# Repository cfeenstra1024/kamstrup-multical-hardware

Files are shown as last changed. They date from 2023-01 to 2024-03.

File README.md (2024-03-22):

# Hardware for use with ESPHome and Kamstrup Multical 403

This repository contains a PCB and housing that can be used as the hardware to read the measurements from a Kamstrup Multical 403.
The PCB uses a 'D1 Mini' ESP8266 board. A software component for use in [ESPHome](https://esphome.io/) has been created.

Using this setup you can read measurements from the Kamstrup Multical (e.g. city heating) and publish the measurements to 
[Home Assistant](https://www.home-assistant.io/).

## Electronics
The Kamstrup Multical 403 uses an optical interface for communication. A PCB was designed that uses a mini-D1 ESP8266 board. The 
[PCB Gerbers](Electronics/PCB%20Gerbers) folder contains the 
required files to fabricate the PCB. The [PCB Components](Electronics/PCB%20Components) folder contains the BOM (bill of materials) and the component placement files. A special version for use with [JLCBCB](https://jlcpcb.com/) has been created for these.

The PCB has the following features:
- Optical interface for use with the Kamstrup meter
- Pulse counter (can be used with a proximity sensor to measure water consumption)
- 2 free open collector outputs
- 2 free inputs

### What you need
- Order (or build) the PCB with the transistors and resistors
- [IR LED 940 nm](https://www.amazon.com/HiLetgo-Infrared-Emitter-Receiver-Emission/dp/B00M1PN5TK)
- [IR Photo Diode 940 nm](https://www.amazon.com/HiLetgo-Infrared-Emitter-Receiver-Emission/dp/B00M1PN5TK)
- [D1 Mini ESP8266 board](https://www.amazon.com/Organizer-ESP8266-Internet-Development-Compatible/dp/B081PX9YFV)
- Optional: [Header pins](https://www.amazon.com/MCIGICM-Header-2-45mm-Arduino-Connector/dp/B07PKKY8BX)

### Images
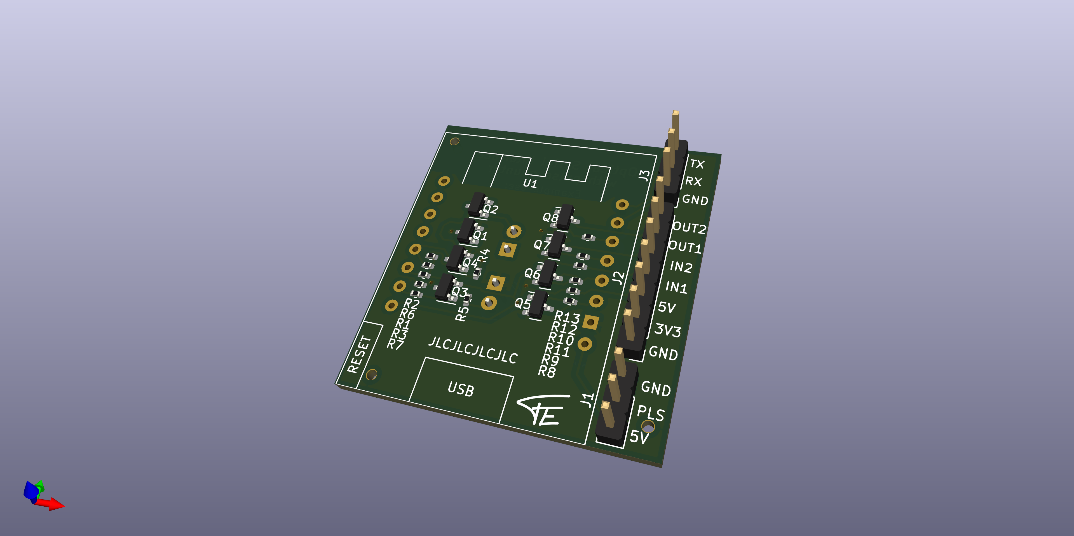
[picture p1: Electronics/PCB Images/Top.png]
PCB Top

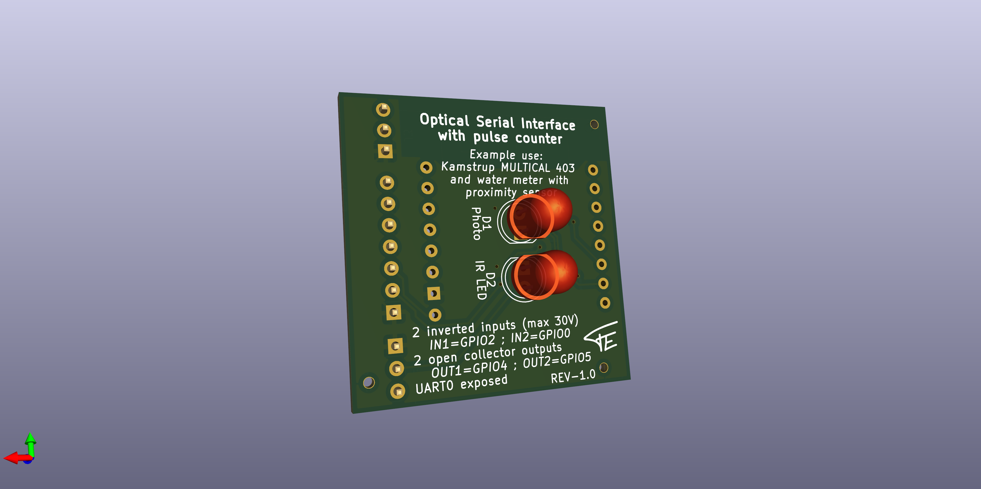
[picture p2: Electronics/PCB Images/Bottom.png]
PCB Bottom


## Housing

The housing can be 3D printed with a regular 3D printer. The [Fusion 360](Housing/Fusion-360) design and [STL](Housing/STL) files are provided.

The Kamstrup Multical 40x meter needs to be waken up by pressing a button. It then stays awake for a few minutes. To keep the meter awake, magnets must be placed 
in the 4 holes. Every hole fits 2 magnets (using a total of 8).

### What you need
- PCB printer to print the 2 STL files (housing and lid)
- 8x [6x3 mm neodymium magnets](https://www.amazon.com/MIN-Neodymium-Small-Magnets-6mm/dp/B096LZNZTQ)

### Images
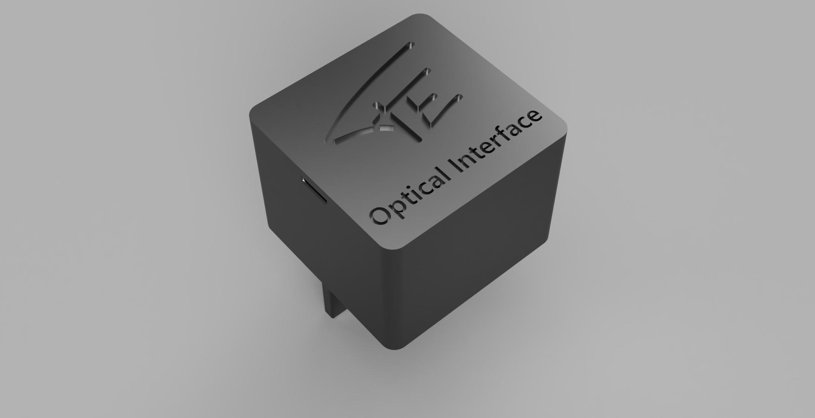
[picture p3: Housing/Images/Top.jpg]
Housing Top

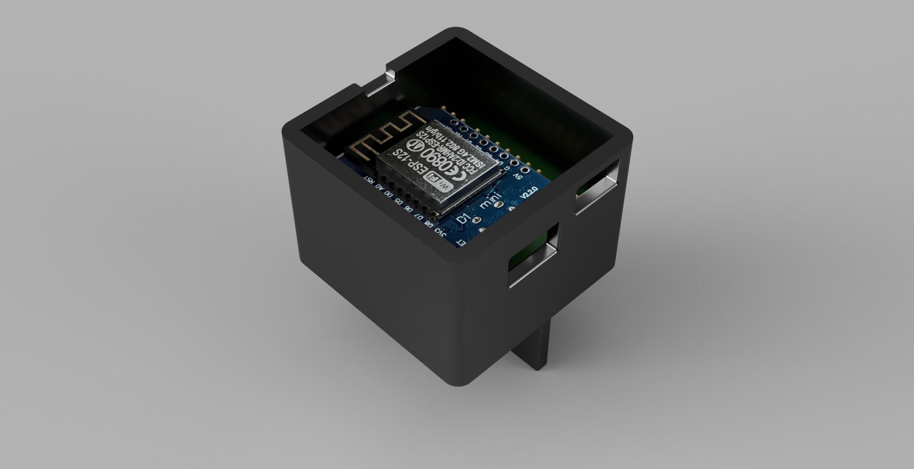
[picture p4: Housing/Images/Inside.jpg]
Housing Inside

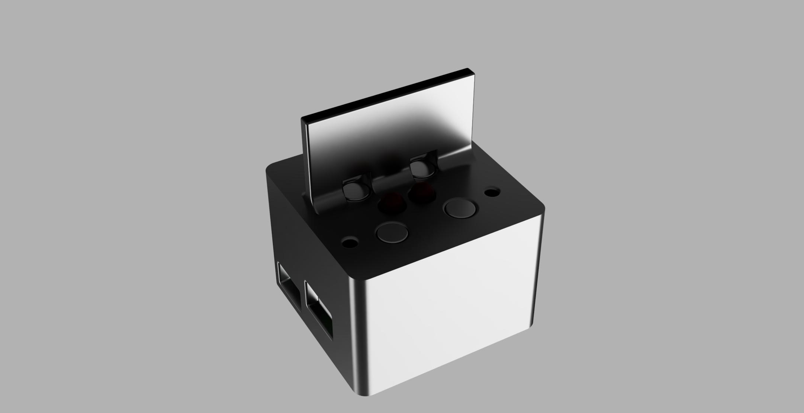
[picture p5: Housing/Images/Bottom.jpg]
Housing Bottom


## Software

Use the `kamstrup_kmp` component in ESPHome. Refer to the [Documentation](https://esphome.io/components/sensor/kamstrup_kmp) for all details regarding this component.

Example config file:
```yml
uart:
  baud_rate: 1200
  stop_bits: 2
  tx_pin: GPIO15
  rx_pin: GPIO13

sensor:
  - platform: kamstrup_mc40x
    heat_energy:
      name: 'Heat Energy'
    power:
      name: 'Heat Power'
    temp_diff:
      name: 'Heat Temperature Difference'
    flow:
      name: 'Heat Flow'
    custom:
      - name: Custom Heat Energy
        command: 0x003C
      - name: Custom Heat Power
        command: 0x0050
    update_interval: 60s
```

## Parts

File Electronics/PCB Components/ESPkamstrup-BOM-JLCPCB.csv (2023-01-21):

Comment | Designator | Footprint
S9013 J3 | Q8,Q2,Q4,Q5,Q1,Q7,Q6 | SOT-23
Conn_01x03_Male | J1,J3 | PinHeader_1x03_P2.54mm_Vertical
S9015 | Q3 | SOT-23
ESP8266_D1mini | U1 | ESP8266_D1mini
10k | R2,R8,R6,R11,R1 | R_0402_1005Metric
100 | R5 | R_0402_1005Metric
 | ,,
Conn_01x07_Male | J2 | PinHeader_1x07_P2.54mm_Vertical
39k | R12,R10,R9,R13,R7,R4 | R_0402_1005Metric
15k | R3 | R_0402_1005Metric
D_Photo | D1 | LED_D5.0mm
IR LED | D2 | LED_D5.0mm

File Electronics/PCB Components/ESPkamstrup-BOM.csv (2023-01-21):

Id | Designator | Package | Quantity | Designation | Supplier and ref
1 | Q8,Q2,Q4,Q5,Q1,Q7,Q6 | SOT-23 | 7 | S9013 J3
2 | J1,J3 | PinHeader_1x03_P2.54mm_Vertical | 2 | Conn_01x03_Male
3 | Q3 | SOT-23 | 1 | S9015
4 | U1 | ESP8266_D1mini | 1 | ESP8266_D1mini
5 | R2,R8,R6,R11,R1 | R_0402_1005Metric | 5 | 10k
6 | R5 | R_0402_1005Metric | 1 | 100
7 | ,, |  | 3
8 | J2 | PinHeader_1x07_P2.54mm_Vertical | 1 | Conn_01x07_Male
9 | R12,R10,R9,R13,R7,R4 | R_0402_1005Metric | 6 | 39k
10 | R3 | R_0402_1005Metric | 1 | 15k
11 | D1 | LED_D5.0mm | 1 | D_Photo
12 | D2 | LED_D5.0mm | 1 | IR LED

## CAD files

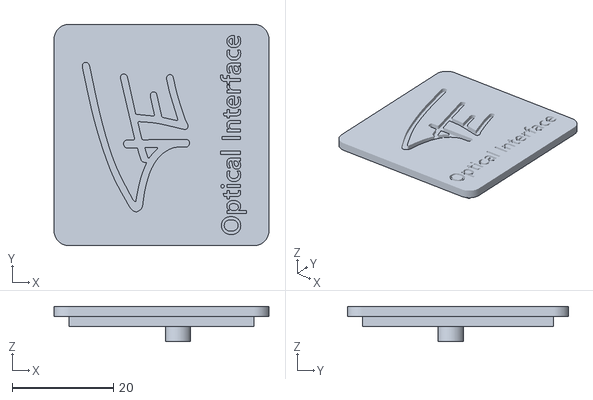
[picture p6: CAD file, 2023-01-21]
Housing/STL/Lid.stl
42.6 x 43.8 x 7.00

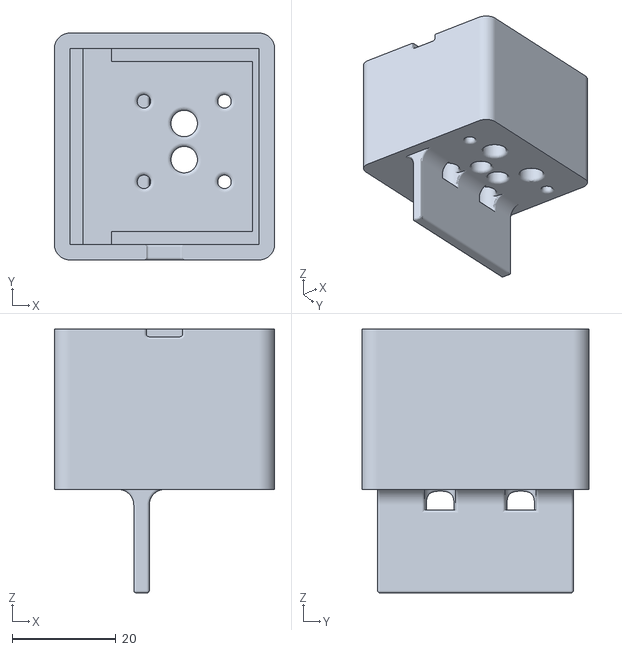
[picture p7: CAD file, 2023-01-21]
Housing/STL/Housing.stl
42.6 x 43.8 x 51.0

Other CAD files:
Housing/Fusion-360/Kamstrup Multical 403.f3z

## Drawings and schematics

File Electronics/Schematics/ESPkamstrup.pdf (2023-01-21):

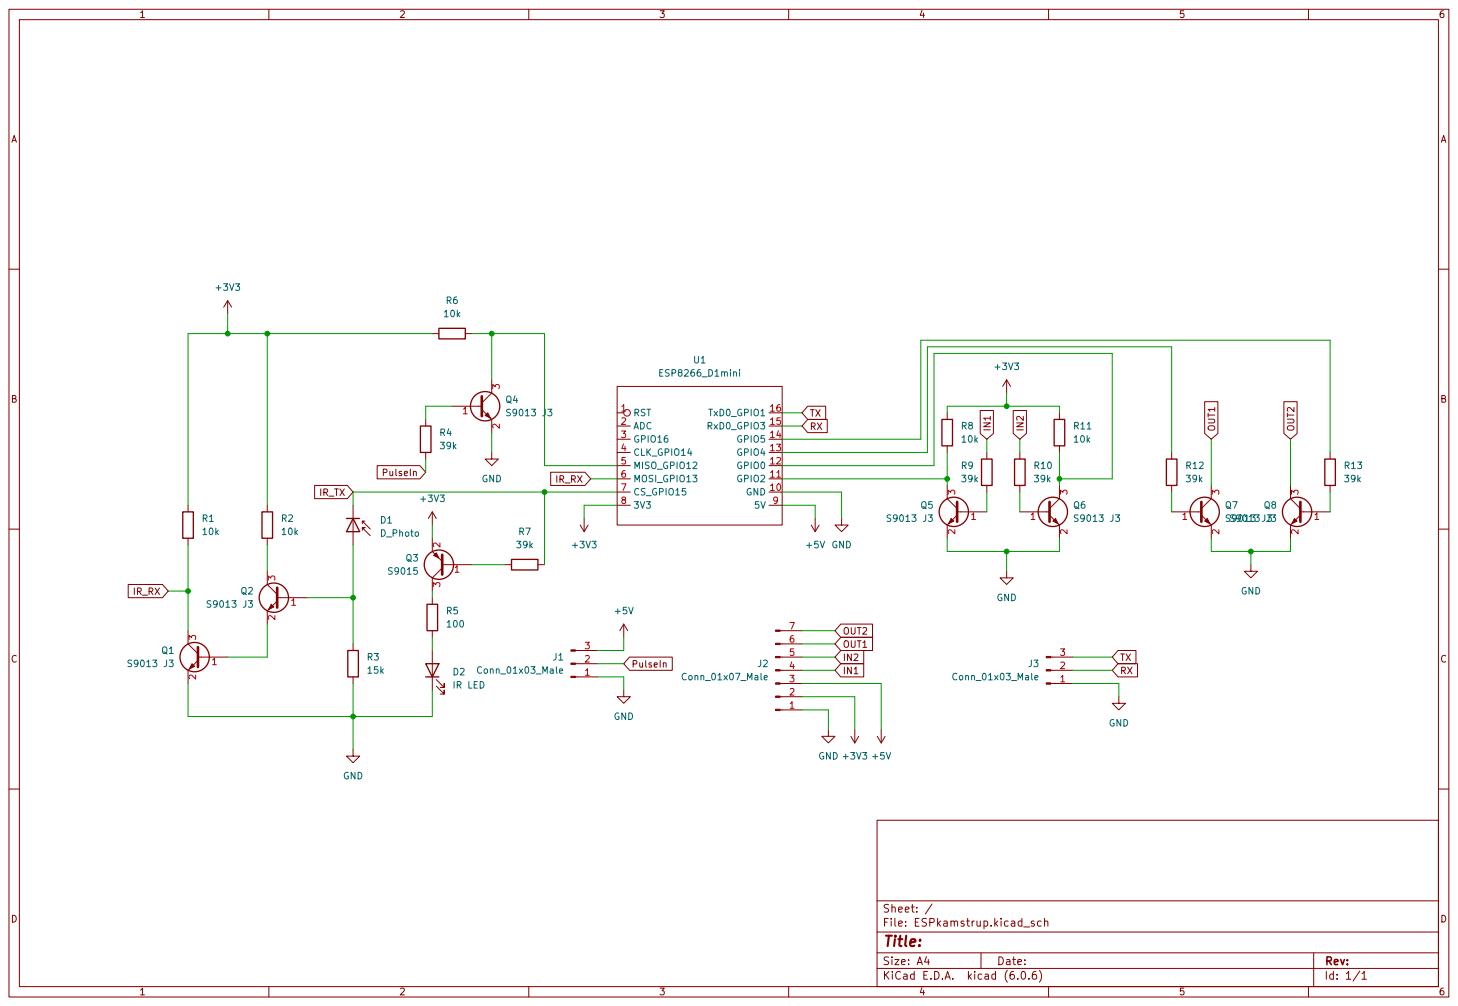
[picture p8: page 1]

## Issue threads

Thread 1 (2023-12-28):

Improve component with extra registers for multiple device types

htvekov, 2023-12-28:
Hi' @cfeenstra1024

Still waiting for the ESPHome PR to be merged before testing 🙂
I'm currently using ESPHome with my own 'tweaked' version of @cenobitedk Kamstrup custom component. Both for my district heating meter (Multical 602) as well as my water meter (flowIQ 2200).

I would suggest that you add the High Resolution register(s) to your component as well. For the x03 meter series it's a straight forward process. For the x02 series it's a bit more complicated as the HiRes register is a delta value. I've also added a calculated yearly cooling average sensor. Very useful in countries where the utility companies enforce 'penalty' tariffs for customers not cooling the water sufficiently. Reading the Unit Of Measurement from the actual device would also be a nice feature (not sure if you've already done that ?)

You could take a peek at my [fork](https://github.com/htvekov/esphome_multical402) if you're interested 🙂

cfeenstra1024, 2024-01-02:
Hi @htvekov,

Nice, you have different meters than I have. I only have a Multical 403. The component I created has native support for some of the most common registerers like 'Heat Energy' and 'Power'. However, you can add any number of registers yourself using the config file. See an example below that reads the high resolution register you've mentioned. I did not really want to add all possible registers in the component, but instead allow the (advanced) user to enter the register IDs themselves.

Once the PR is merged, I am open to extending the list of sensors. But I'm really keen to have this component first in ESPHome, before I disturb reviewers with more commits ;)

I also thought about using the unit read from the device, and set that to the sensor. However, this seems not to be possible / allowed. After I'd created this, I received [some comments](https://github.com/esphome/esphome/pull/4200#pullrequestreview-1347750261) about that in the PR.

A documentation PR is also pending, explaining the config options. As long as this PR is open, you can check it out [here](https://deploy-preview-3513--esphome.netlify.app/components/sensor/kamstrup_kmp).

```yaml
uart:
  baud_rate: 1200
  stop_bits: 2
  tx_pin: GPIO15
  rx_pin: GPIO13

sensor:
  - platform: kamstrup_kmp
    heat_energy:
      name: 'Heat Energy'
    power:
      name: 'Heat Power'
    temp_diff:
      name: 'Heat Temperature Difference'
    flow:
      name: 'Heat Flow'
    temp1:
      name: 'Temp 1'
    temp2:
      name: 'Temp 2'
    volume:
      name: 'Volume'
    custom:
      - name: 'High Resolution Heat Energy'
        command: 0x010A
        unit_of_measurement: 'Wh'
      - name: 'Some other custom sensor (Power)'
        command: 0x0050
```

cfeenstra1024, 2024-01-04:
I'll think about how I can add the different registers in a way the code stays maintainable and the configuration in the yaml file is not too complex.
The custom sensor supports any number of registers (it is a list). So no limitation to 5 any more.

htvekov, 2024-01-04:
For the Kamstrup FlowIQ 2200 meter following registers imo are the most relevant. Flow and volume registers are identical with the 40x/60x meters.

As this meter can detect both leak, burst, dry and tamper I'm currently searching for relevant Multical 21/FlowIQ 2x00 meter register info. So far I've not been able to find any info that confirms that these actually are the right registers for the info bit register and the reverse flow. The three lsb's should represent the actual event. Remaining bits should be a 'coarse' time indication for the duration. I'm not really keen to do a real life test on the information register - simulating a leak by running the tap for 24 hours 😉

The meter should also be able to report both ambient- and inlet water average temperature. I'm currently trying to identify these registers manually. So far no luck. But I've identified other registers such as max. flow pr. day etc.

```
0x00F3, // 0243 - V1 reverse flow					UOM 0x0028 (40 dec.): 'm³'
0x004A, // 0074 - Current water flow	 			UOM 0x0029 (41 dec.): 'l/h'
0x0044, // 0068 - Volume register V1				UOM 0x0028 (40 dec.): 'm³'
0x0063, // 0099 - Information						UOM 0x0033 (51 dec.): 'No unit'
0x03EC  // 1004 - Operating hour counter			UOM 0x002E (46 dec.): 'h'
```

htvekov, 2024-01-04:
I would still add the district heating HiRes Energy register though. This is highly usable to get more precise and detailed hourly readings e.g. in HA's Energy dashboard. Confirmed working on the new meter series. Not really sure what register the 402 meter is using. Should be 0x009B, but not confirmed.

```
0x010A, // 266 - Heat energy - Multical 403/603 High resolution (1 Wh)
0x009B  // 155 - Heat energy - Multical 602 High resolution (0.01 kWh)
```

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

htvekov, 2024-01-05:
Well, it seems that the HiRes register values differs depending on utility company/country.

If you check the cross referenced link further up this thread, two users have confirmed that the HiRes register is working as expected.

A Danish guy with a 403 meter (configured to return energy consumption in kWh). Here the HiRes register is also reported in kWh but with 3 decimals.
Also Dutch guy using a 603 meter with consumption i GJ for the 'normal' energy register. Here the HiRes register is reported in MWh with 5 decimals.

It seems that your HiRes register is returning a 'delta' value just a I get with my 602 meter. I guess that I've triggered my register at some point when I first attached the IR optical head - And it has been running ever since (4 months or so).
Upon ESPHome boot I deduct the HiRes register from the 'normal' energy register and store that difference as a constant. I add that constant to the HiRes register and return that value as my 'real' HiRes register.

cfeenstra1024, 2024-03-22:
FYI : The component has been merged and is now part of ESPHome (version >= 2024.3.0)

cenobitedk, 2024-03-22:
That's awesome @cfeenstra1024 💯

Closed 2024-05-02.

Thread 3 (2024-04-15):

jlcpcb BOM not working anymore + CPL file missing

sboldt1978, 2024-04-15:
Hi,

this is a really great project and I would like to implement this in my home as well - ordered via jlcpcb. I don't know if the changed something in the input files format, but now they request a CPL file (Pick&Place File) which I cannot find in the github files. Futhermore in the BOM file there are several components that cannot be matched (even when I use the special jlcpcb file. Can someone with better electronic knowledge than I have please update the BOM file and add the CPL file so that I - and everyone else who will get the stuff from jlcpcb.com can be sure to order the right parts?

Thanks a lot in advance!

best regards,
Stephan

frustreermeneer, 2024-04-16:
@sboldt1978 If you figure it out, maybe we can buy together?

cfeenstra1024, 2024-04-16:
I'll try to find some time to update the production files.
It is possible to order still, but you need to do some manual steps:

* Zip all files in the *PCB Gerbers* folder
* Upload the zip on JLCPCB
* Use the default settings, except for:
  * Set *Remove Order Number* to *Specify a location*
  * Enable the *PCB Assembly* option
  * Set *Tooling holes* to *Added by Customer*
* In the assembly wizard, you need to upload a BOM and CPL file:
  * BOM file is: *Electronics\PCB Components\ESPkamstrup-BOM-JLCPCB.csv*
  * CPL file is: *Electronics\PCB Components\ESPkamstrup-all-pos-JLCPCB.csv*
* See screen shot below for the component numbers I have used in my order (the C-numbers in the 'Matched Part Detail' column)
* In the *Component Placements* tab, check that all components are placed correctly. By default the transistors are rotated 180 degree. So do correct those. Select one and hit the spacebar twice to rotate. See screen shot below on how this should look at the end.

Sorry for the inconvenience. I will update the production files so all of the above will be set correctly automatically, but I cannot promise when I've time for this.

BTW: I do have a couple of these PCBs available. I could send you one if the shipping costs are reasonable from the Netherlands. If interested, please PM me through the [Home Assistant commutity](https://community.home-assistant.io/u/cfeenstra/summary).

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

sboldt1978, 2024-04-16:
Hi @cfeenstra1024 ,

I live in Germany, so shipping costs should be not too high from NL :-) May be I'm too stupid but I didn't find a way to send you a pm through the HA community :-( Can you please drop me a message here: https://community.home-assistant.io/u/sboldt1978/

Thanks a lot and best regards,
Stephan

frustreermeneer, 2024-04-16:
>  May be I'm too stupid but I didn't find a way to send you a pm through the HA community :-( Can you please drop me a message here: https://community.home-assistant.io/u/sboldt1978/

I have the same, you can't send PM's when you're new i guess.
My profile is https://community.home-assistant.io/u/frustreermeneer/
I'm not sure if i can receive PM's though...

morotsgurka, 2024-09-24:
Hi! I've updated the files in PR #5 with these changes it should fix all problems mentioned in this issue regarding ordering from JLCPCB. Hope it helps!

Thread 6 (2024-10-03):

GPIO pins valid?

MTrab, 2024-10-03:
I have ordered this PCB from JLCPCB and assembled the remaining (IR emitter and receiver along with PIN headers) by hand.
When flashing my D1 Mini with the code, the IR emitter isn't blinking (checking thru camera)
If I supply the IR emitter with 3v3 directly, I can see it light up (again thru camera)

Is the GPIO pins mentioned in the Readme still valid?

Polarity have been double and triple checked

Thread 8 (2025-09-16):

Board is not working with Kamstrup Multical 603

teunaldo, 2025-09-16:
I have the board let build by JLC-PCB.com but I don't get a reaction from Kamstrup.
I use a WEMOS D1 Mini v3.1.0

The code I use is:
```
esphome:
  name: dsmr-kamstrup-meter2
  friendly_name: dsmr-kamstrup-meter2

esp8266:
  board: esp01_1m
# Enable logging
logger:
  level: DEBUG  # Logging costs performance, switch to DEBUG when needed only
  baud_rate: 0 # disable logging over uart (would use up a HW uart)
# Enable Home Assistant API
api:
  encryption:
    key: "***************************************"

ota:
  - platform: esphome
    password: "***************************************"

wifi:
  ssid: !secret wifi_ssid
  password: !secret wifi_password

  # Enable fallback hotspot (captive portal) in case wifi connection fails
  ap:
    ssid: "Dsmr-Kamstrup-Meter2"
    password: "***************************************"

captive_portal:

# Web server for local access
web_server:
  port: 80
uart:
    id: uart_bus
    rx_pin: GPIO13
    tx_pin: GPIO15
    baud_rate: 1200
    data_bits: 8
    parity: NONE
    stop_bits: 2

 sensor:
   - platform: kamstrup_kmp
     heat_energy:
       name: Heat Energy
     power:
       name: Heat Power
     temp_diff:
       name: Heat Temperature Difference
     flow:
       name: Heat Flow
       custom:
       - name: Custom Heat Energy
         command: 0x003C
       - name: Custom Heat Power
         command: 0x0050
     update_interval: 20s
```

When I look with a phone into the LED, I see a purple glow blinking when it requests for information so that looks fine.
I had this in the past working on my Rpi with a IR eye, so it looks like the Kamstrup is doing fine.
(https://github.com/matthijsvisser/kamstrup-402-mqtt)
